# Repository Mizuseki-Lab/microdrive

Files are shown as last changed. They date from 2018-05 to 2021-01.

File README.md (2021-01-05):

# microdrive
Microdrive designs for silicon probes 

The .stl files are optimized for Asiga Pico2 HD with NextDent Model.
For other printers and/or resins, some adjustment may be needed.

The drive is designed for a 1/2-inch 00-90 screw and a metal pole taken from a post terminal strip.
The attachment is intended to be used with 3/8-inch 00-90 screws.  
To build the variangle attachment, 1/4-inch 000-120 screws and nuts are also needed.

Quick instructions are avirable at https://github.com/Mizuseki-Lab/microdrive/tree/master/instructions

* * *
The original idea of the drive is described in the following paper.

Micro-drive and headgear for chronic implant and recovery of optoelectronic probes
Jinho Chung, Farnaz Sharif, Dajung Jung, Soyoun Kim & Sebastien Royer
Scientific Reports volume 7, Article number: 2773 (2017)
doi:10.1038/s41598-017-03340-5
https://www.nature.com/articles/s41598-017-03340-5

The designs are desitributed under GNU GPLv3 license.
The source file in f3d format can be found at https://github.com/Mizuseki-Lab/microdrive/tree/master/f3d

* * *
Further customization has been done by Mihály Vöröslakos.
His design files are avirable at https://github.com/buzsakilab/3d_print_designs/tree/master/Microdrives/Plastic_recoverable

Also elaborated instraction videos are on youtube, which is helpful to build our dirve as well
1. Microdrive assembly:  https://youtu.be/rjxaH515N64 
2. Probe attachment to microdrive:  https://youtu.be/2L5RHcbsU7o 
3. Probe recovery:   https://youtu.be/T5gyuZVKXo8

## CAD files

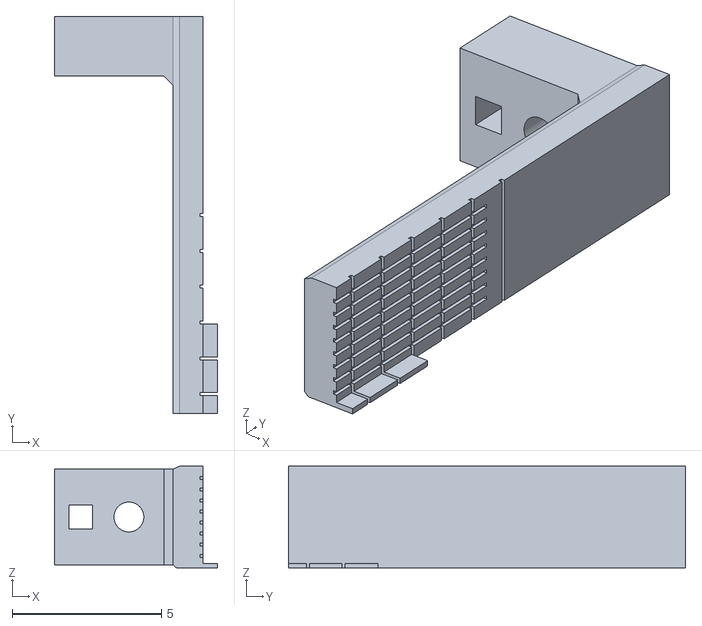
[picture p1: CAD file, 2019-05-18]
basic/arm.stl
5.47 x 13.3 x 3.41

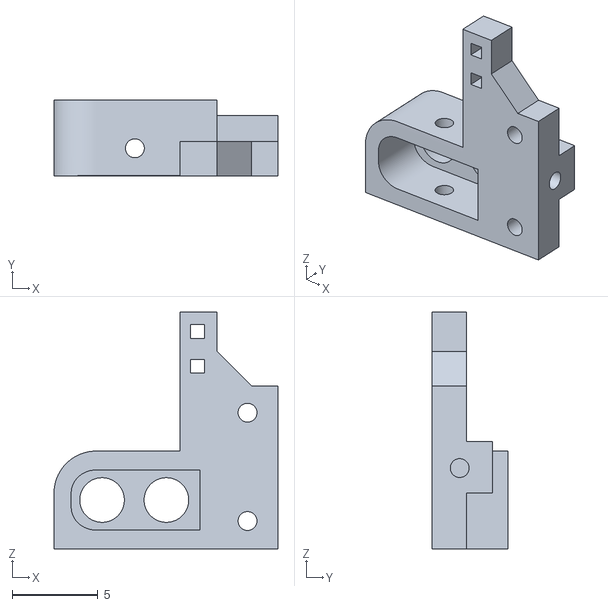
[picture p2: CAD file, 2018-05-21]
variations/holder-side-flip.stl
13.0 x 4.40 x 13.8

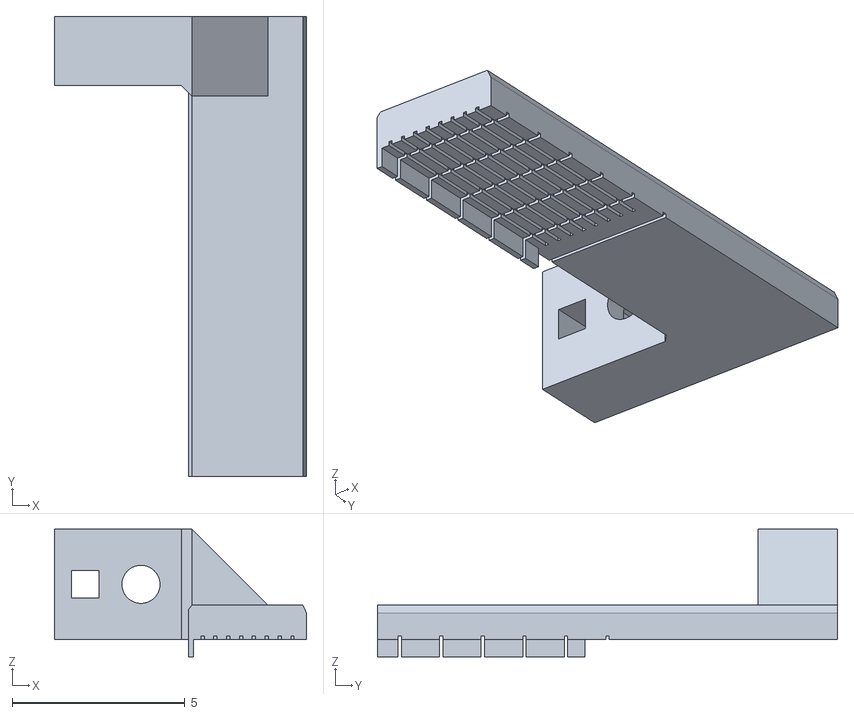
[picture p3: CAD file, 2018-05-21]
variations/w_nut/arm-perpendicular.stl
7.29 x 13.3 x 3.70

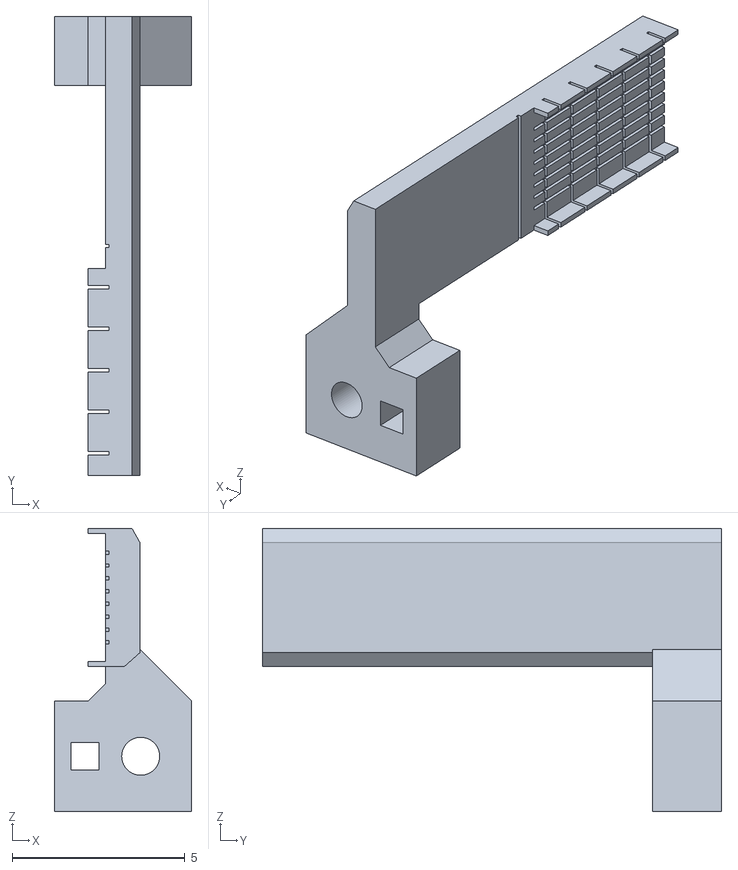
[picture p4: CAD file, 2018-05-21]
variations/wide_arms/wideArm-side-flip.stl
3.98 x 13.3 x 8.20

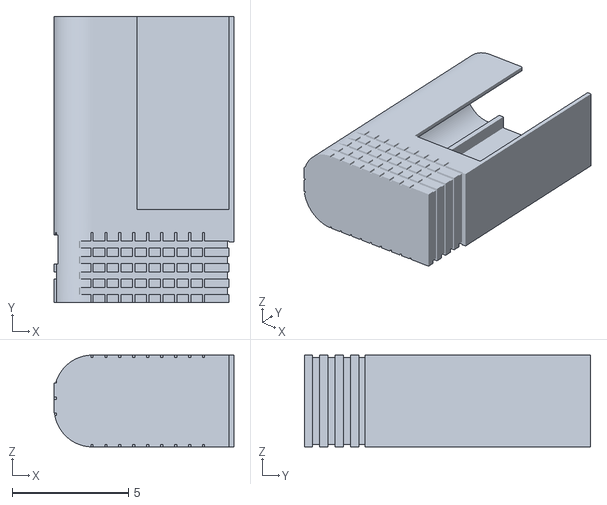
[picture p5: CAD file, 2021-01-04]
ver181005/base-side.stl
7.73 x 12.3 x 3.95

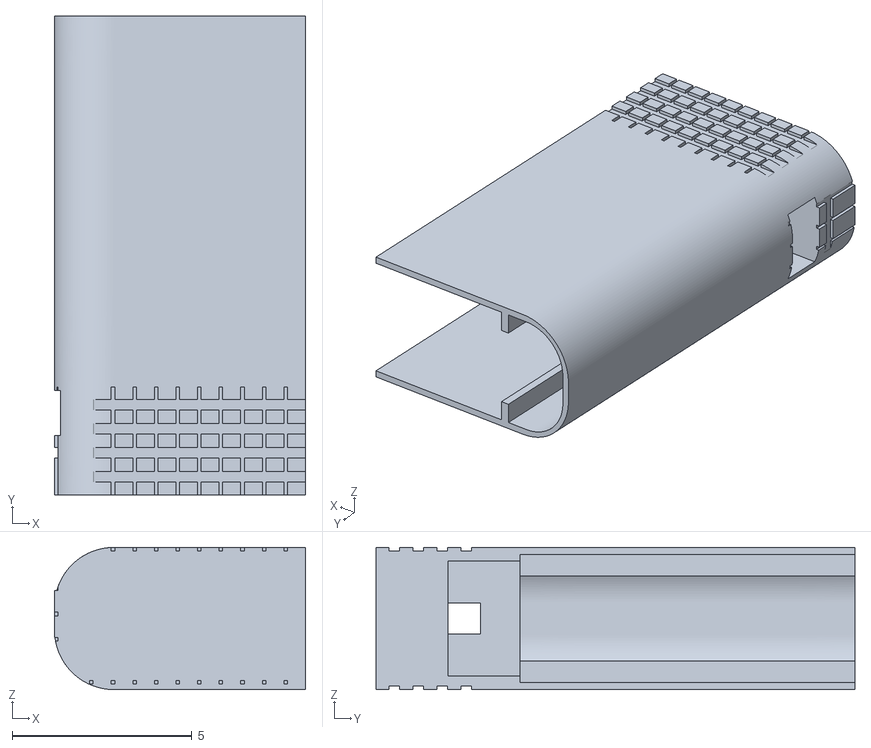
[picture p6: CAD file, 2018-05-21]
basic/base.stl
6.97 x 13.3 x 3.95

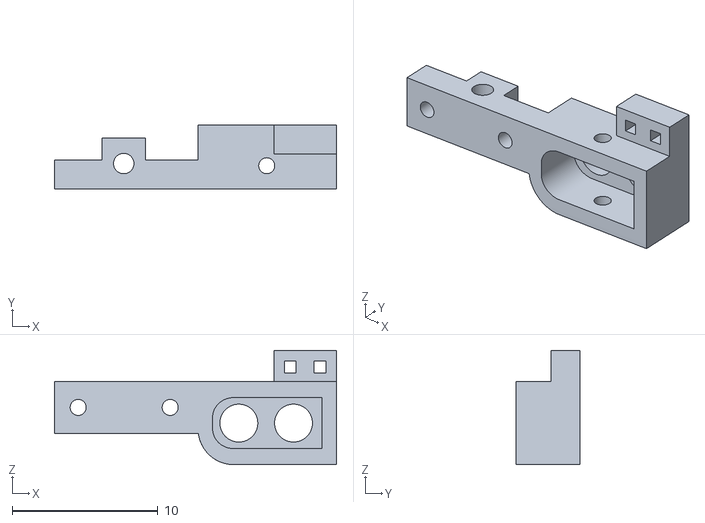
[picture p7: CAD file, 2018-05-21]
variations/holder-far.stl
19.4 x 4.40 x 7.84

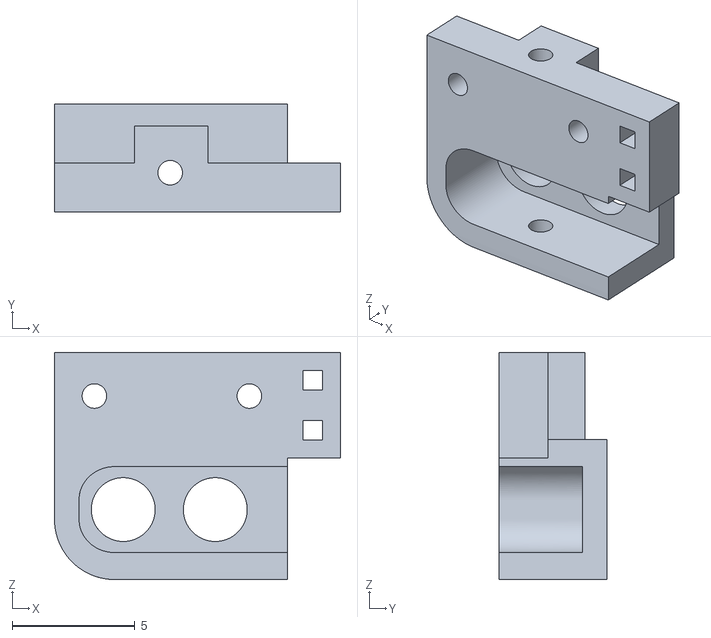
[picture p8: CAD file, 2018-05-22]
variations/open-end/holder.stl
11.7 x 4.40 x 9.25

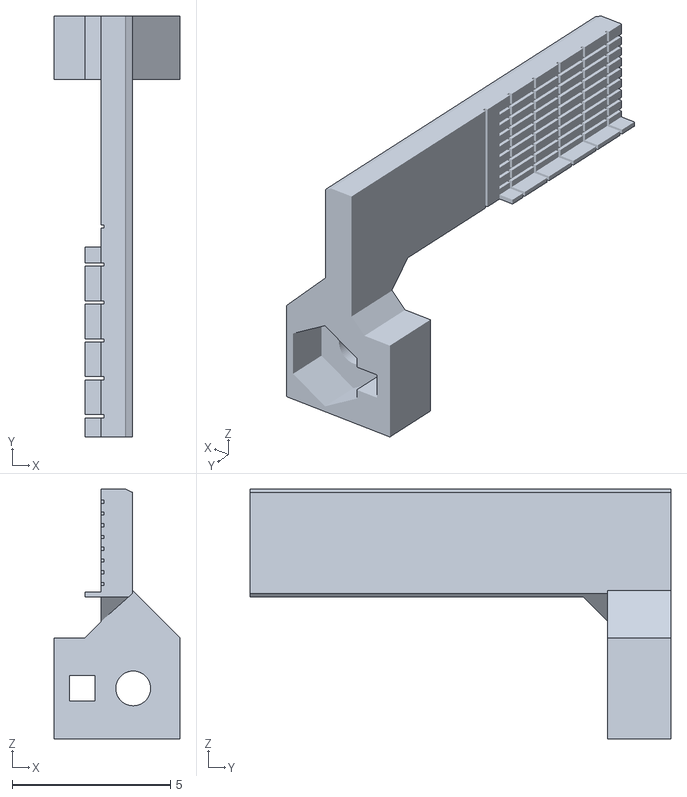
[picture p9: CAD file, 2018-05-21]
variations/w_nut/arm-side-flip.stl
3.98 x 13.3 x 7.90

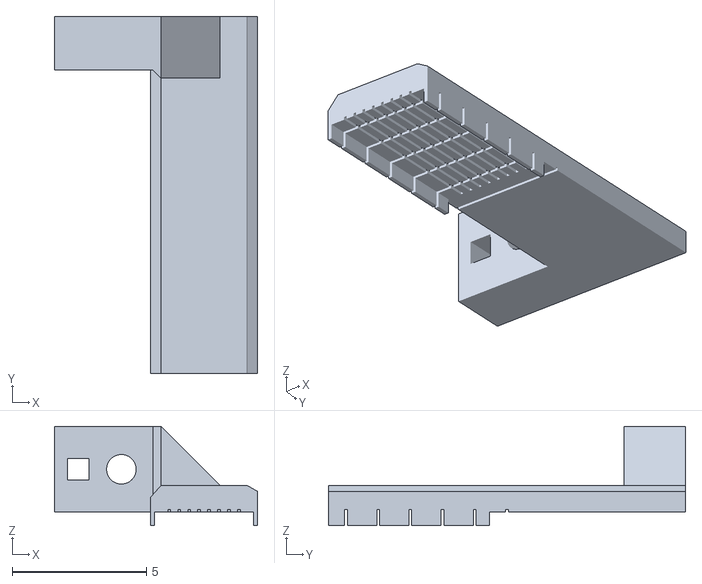
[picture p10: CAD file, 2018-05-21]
variations/wide_arms/wideArm-perpendicular.stl
7.58 x 13.3 x 3.70

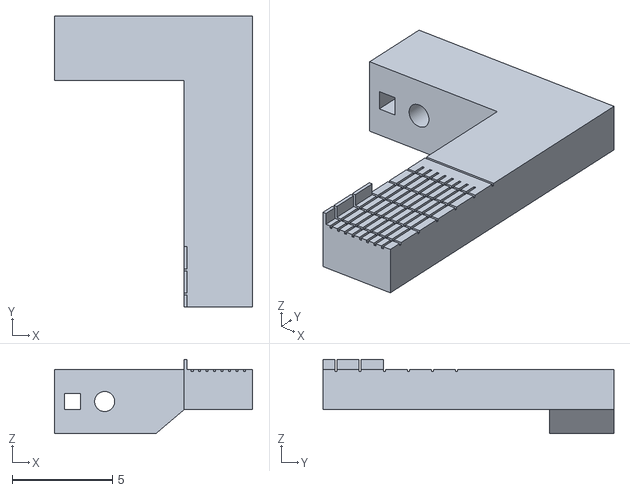
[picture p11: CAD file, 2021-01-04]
ver181005/arm-far-thick.stl
9.88 x 14.5 x 3.70

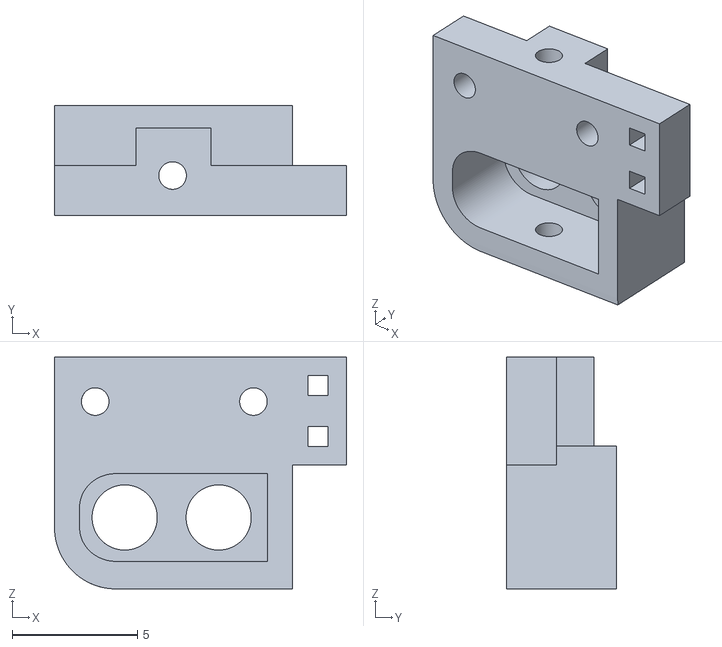
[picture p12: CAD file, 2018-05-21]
basic/holder.stl
11.7 x 4.40 x 9.25

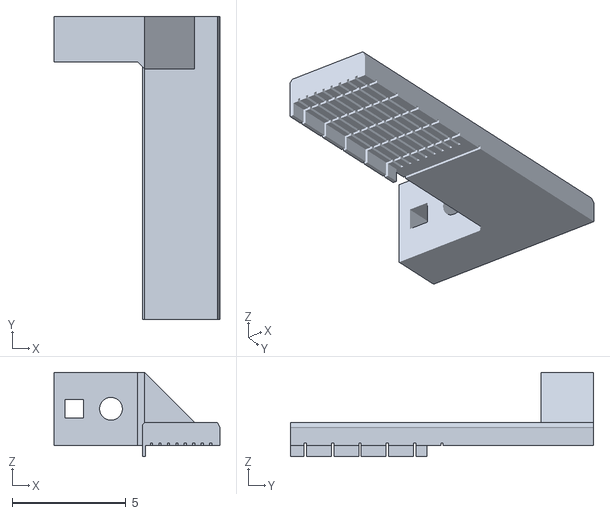
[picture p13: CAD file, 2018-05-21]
variations/arm-perpendicular.stl
7.29 x 13.3 x 3.70

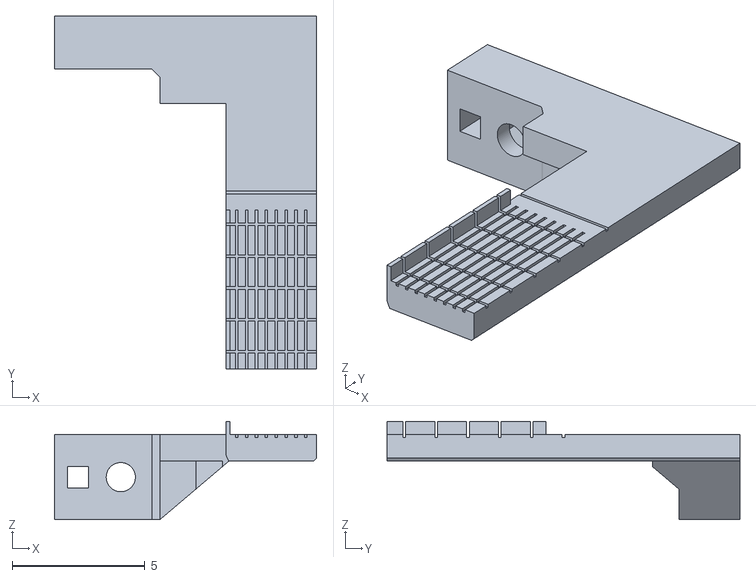
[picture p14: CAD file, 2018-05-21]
variations/w_nut/arm-far.stl
9.88 x 13.3 x 3.70

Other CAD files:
variations/wide_arms/wideArm-far.stl
ver181005/arm-side-flip-thick.stl
basic/attachment.stl
variations/arm-thinTip.stl
basic/drive.stl
f3d/MicrodriveBasic.f3d
f3d/microDrive181005.f3d
variations/arm-far.stl
variations/arm-side-flip.stl
variations/base-side.stl
variations/open-end/holder-far.stl
variations/open-end/holder-mirror.stl
variations/temporal-support.stl
variations/w_nut/arm.stl
variations/wide_arms/wideArm.stl
ver181005/arm-perpendicular-thick.stl
ver181005/base.stl
ver181005/drive-rev2.stl
ver181005/holder-far.stl
ver181005/holder-mirror.stl
ver181005/temporal-support.stl
ver181005/variangle-attachment_linker.stl

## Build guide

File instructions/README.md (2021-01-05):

# quick instructions of the microdrive

## how the assembled drive looks like
Side view  
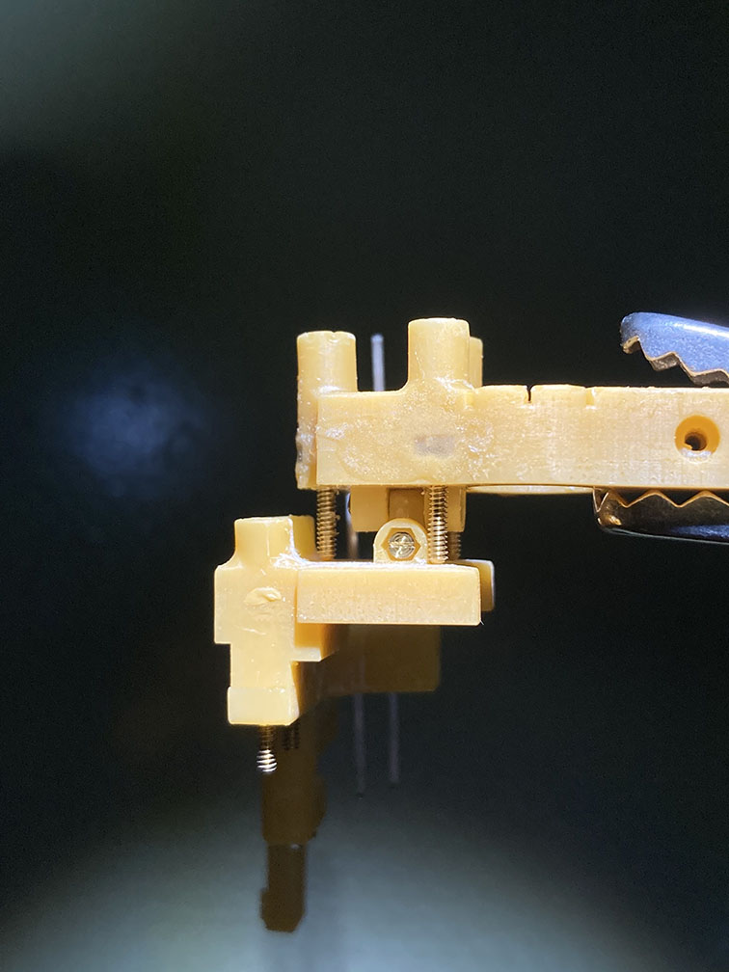
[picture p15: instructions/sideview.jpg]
  

Back view  
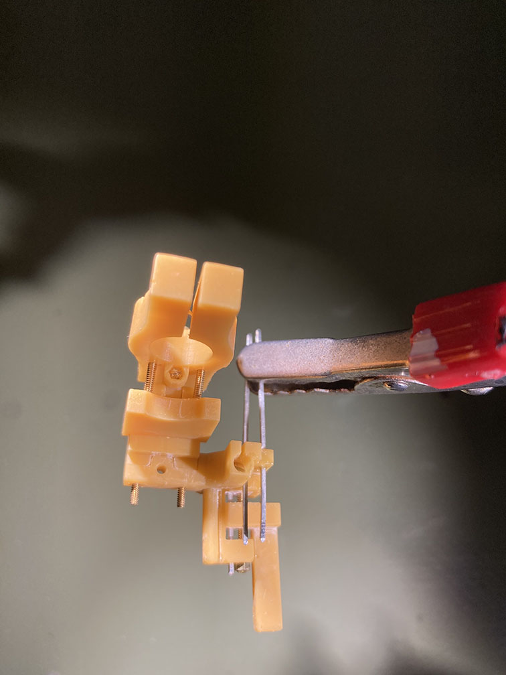
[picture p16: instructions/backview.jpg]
  

## how the drive works
gif showing how the drive works  
[video showing how the drive works](howItWorks.mp4)

## how to assemble
1. put the holder on the drive  
video showing assembling process 1  

2. set the drive on the base  
video showing assembling process 2  

3. put the attachment on the holder  
video showing assembling process 3  

[video showing assembling process](assemble.mp4)

## how to implant the probe (demo with a mock)
1. position the drive on a stereotaxic frame  
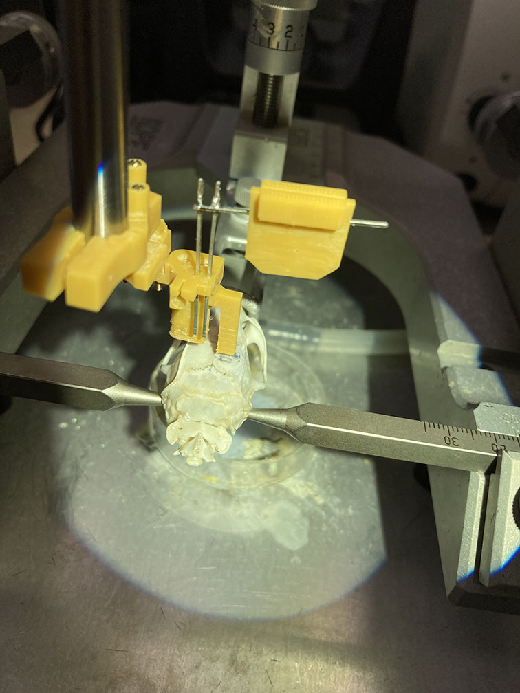
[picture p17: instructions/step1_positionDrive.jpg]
  
2. Fix the drive on the skull (with dental cement)  
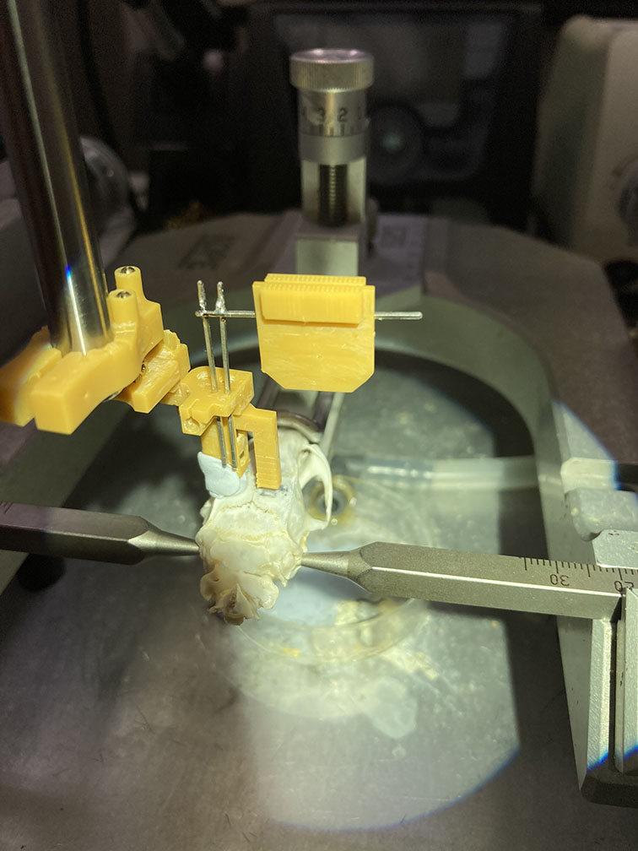
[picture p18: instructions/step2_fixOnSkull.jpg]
  
3. remove attachment from the holder  
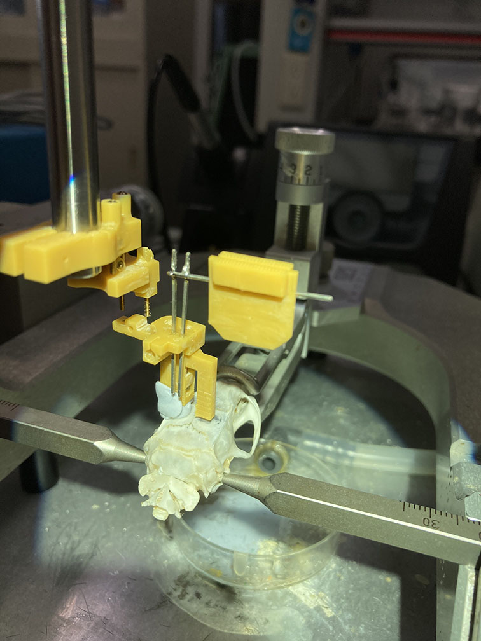
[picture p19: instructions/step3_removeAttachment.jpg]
  
4. de-solder the connector and secure it wherever you want  
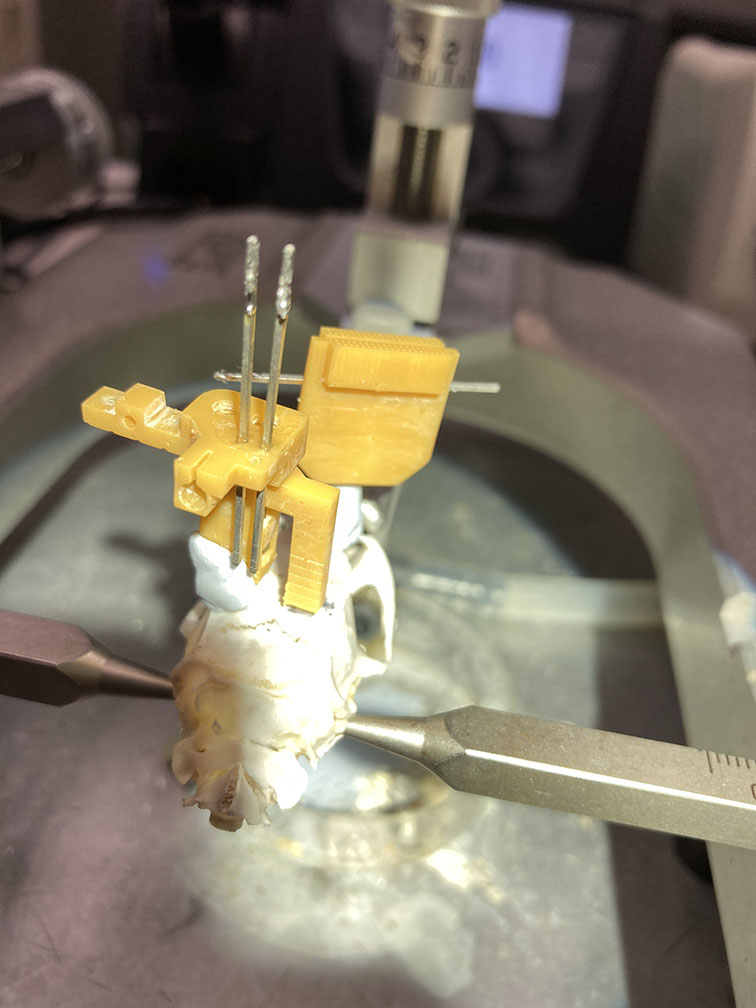
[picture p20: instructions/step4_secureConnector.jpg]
  
5. remove the holder from the drive  
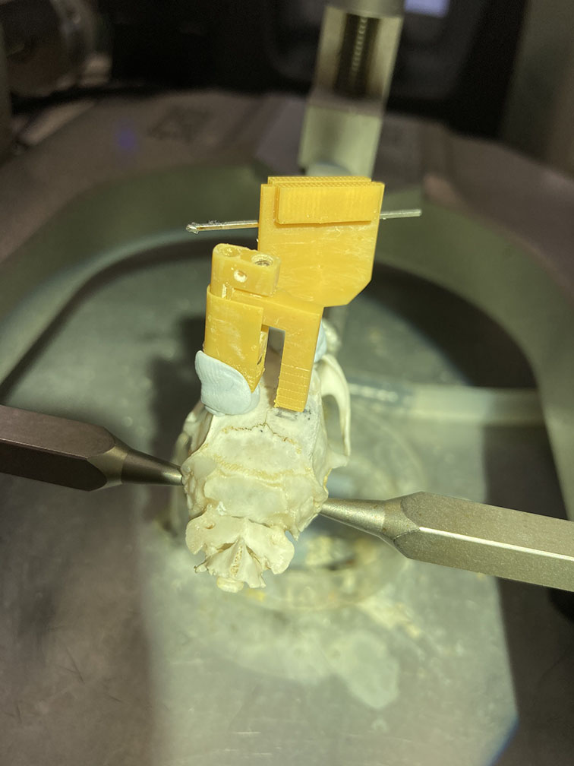
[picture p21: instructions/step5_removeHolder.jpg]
  

## how to recover the drive
1. set the skull on a stereotaxic frame (after perfusion)  
2. put the holder back on the drive  
3. align the attachment (holes on the holder and screws on the attachment can be used as markers)  
4. connect the attachment on the holder  
5. (optional) move up the arms by truning screws  
6. remove a screw connecting the drive on the base  
7. slowly move up the drive with stereotaxic arm  

## how the variangle attachment works
when the screws are loose, the angles can be changed  
gif showing variangle attachment (screws are loose)  
when all 3 screws are pushing the bottom plate, the angle is fixed.  
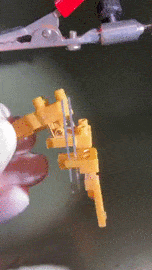
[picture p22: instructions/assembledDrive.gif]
gif showing variangle attachment (screws are tight)
  

One extreme angle  
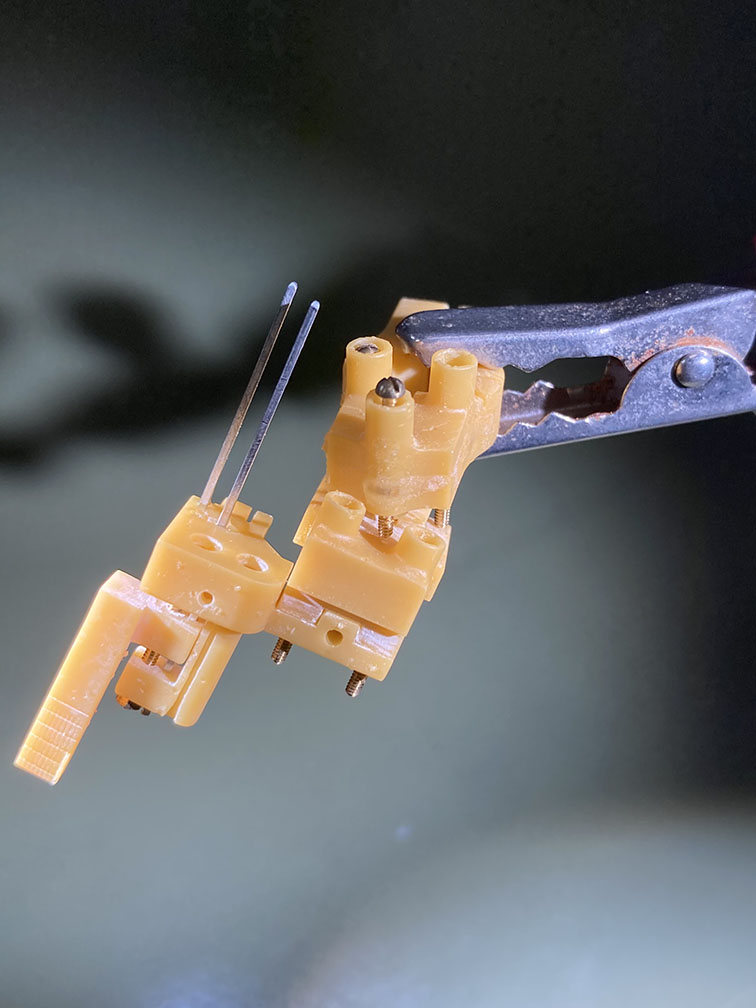
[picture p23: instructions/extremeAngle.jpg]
  

Another extreme angle (the same attachment but different screw positioning)  
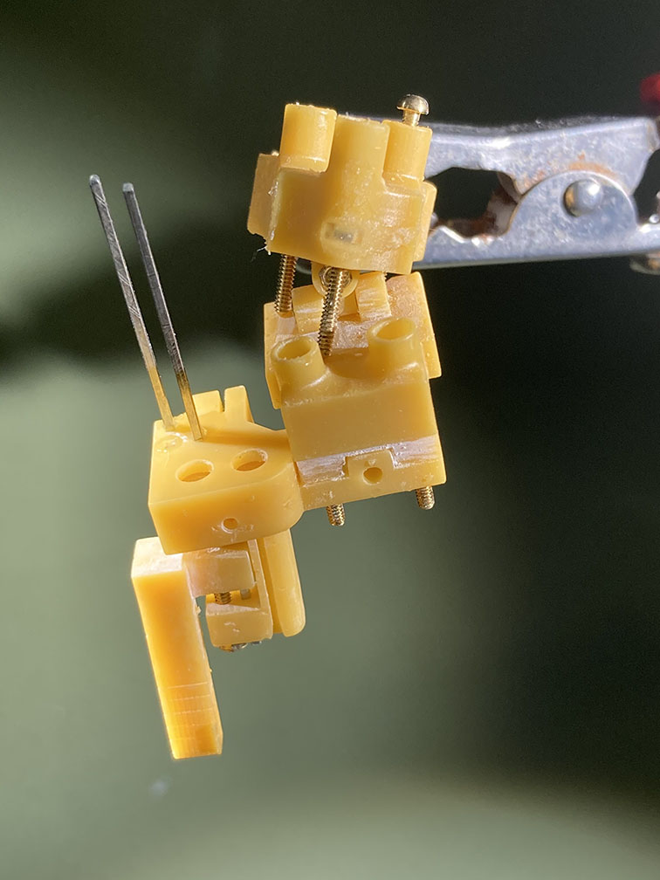
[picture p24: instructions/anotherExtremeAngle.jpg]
  

[video showing variangle attachment (screws are loose)](variangle.mp4)
[video showing variangle attachment (screws are tight)](assembledDrive.mp4)

* * * 
The .stl files are optimized for Asiga Pico2 HD with NextDent Model.
For other printers and/or resins, some adjustment may be needed.

The drive is designed for a 1/2-inch 00-90 screw and a metal pole taken from a post terminal strip.
The attachment is intended to be used with 3/8-inch 00-90 screws.
To build the variangle attachment, 1/4-inch 000-120 screws and nuts are also needed.

The original idea of the drive is described in the following paper.

Micro-drive and headgear for chronic implant and recovery of optoelectronic probes
Jinho Chung, Farnaz Sharif, Dajung Jung, Soyoun Kim & Sebastien Royer
Scientific Reports volume 7, Article number: 2773 (2017)
doi:10.1038/s41598-017-03340-5
https://www.nature.com/articles/s41598-017-03340-5

The designs are desitributed under GNU GPLv3 license.
The source file in f3d format can be found at https://github.com/Mizuseki-Lab/microdrive/tree/master/f3d

* * *
Further customization has been done by Mihály Vöröslakos.
His design files are avirable at https://github.com/buzsakilab/3d_print_designs/tree/master/Microdrives/Plastic_recoverable

Also elaborated instraction videos are on youtube, which is helpful to build our dirve as well
1. Microdrive assembly:  https://youtu.be/rjxaH515N64 
2. Probe attachment to microdrive:  https://youtu.be/2L5RHcbsU7o 
3. Probe recovery:   https://youtu.be/T5gyuZVKXo8

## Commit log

2021-01-04 add vari-angle attachment
    [variangle-attachment_linker.stl]
2021-01-04 add ver181005 of HM
    [arm-far-thick.stl, arm-perpendicular-thick.stl, arm-side-flip-thick.stl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]
2021-01-04 add f3d files
    [MicrodriveBasic.f3d, microDrive181005.f3d]
2021-01-05 add assemble gif
